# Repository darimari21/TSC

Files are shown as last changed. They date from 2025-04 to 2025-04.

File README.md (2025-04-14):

# TSC

Schema:

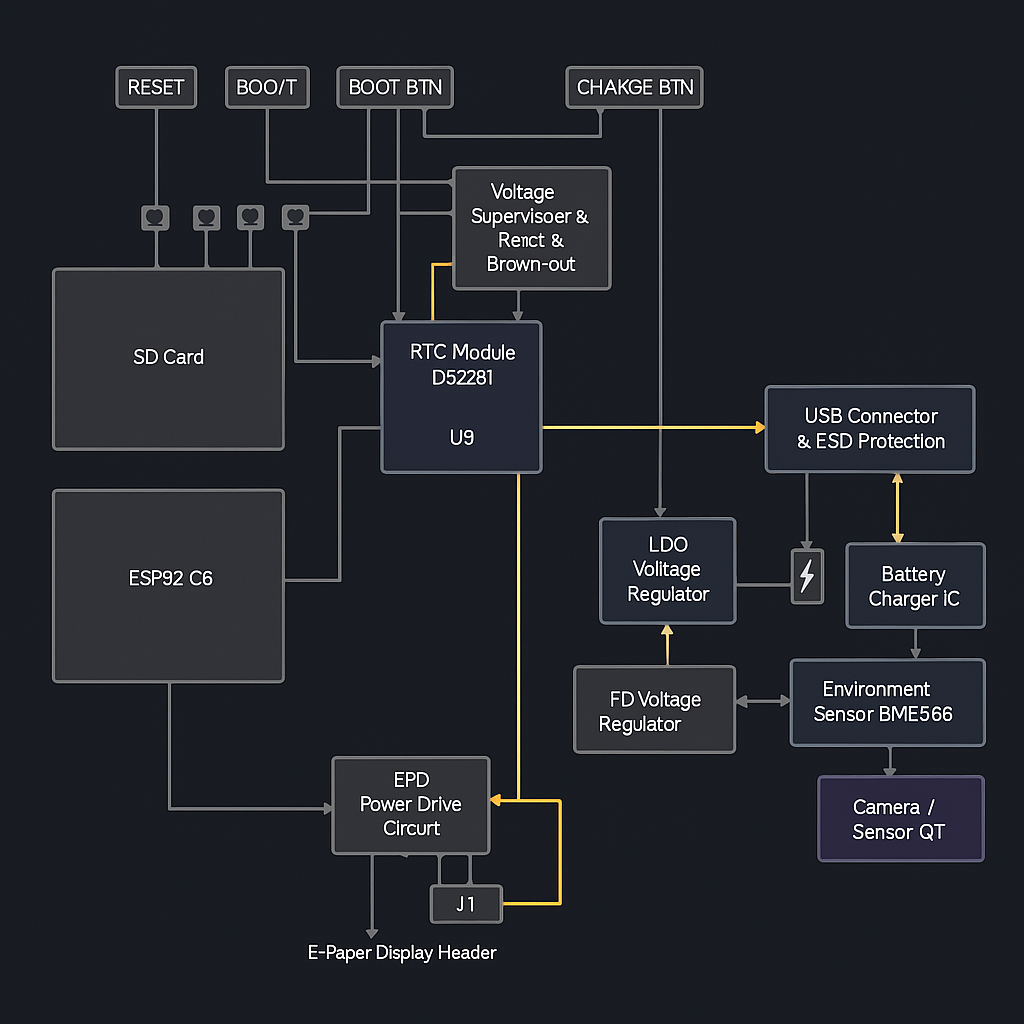
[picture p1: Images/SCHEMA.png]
Diagrama Bloc


Proiectul a început cu realizarea schemei electrice, folosind componentele din biblioteca pusă la dispoziție. După conectare și etichetare, am rulat ERC, corectând majoritatea erorilor (etichete greșite, pini suprapuși), rămânând cu una nedetectată de Fusion.
După finalizarea schemei, am trecut la PCB, decupând placa conform cerințelor și amplasând componentele. Cea mai mare provocare a fost identificarea pieselor și ajustarea unor footprint-uri, precum cel al bobinei L1. După rutare și verificare DRC, am completat cu planurile de masă pe ambele straturi.

Arhitectură Generală a Sistemului
Modulul ESP32-C6-WROOM-1-N8 servește drept unitate principală de control, gestionând comunicația cu celelalte module prin protocoale standard precum I2C, SPI și GPIO. Alimentarea este oferită de o baterie Li-Po, gestionată de un sistem de încărcare și monitorizare a nivelului energetic.

Specificații Hardware

Modul principal – ESP32-C6

Microcontroler cu arhitectură RISC-V, suport Wi-Fi 6 și Bluetooth Low Energy

Interfețe suportate: SPI, I2C, UART, GPIO

Tensiune de alimentare: 3.3V

Sistem de alimentare și monitorizare

MCP73831 – controller pentru încărcarea bateriei Li-Po

MAX17048 – circuit pentru monitorizarea nivelului bateriei (fuel gauge) cu ieșire de alertă

XC6220A331MR – regulator de tensiune pentru stabilizarea la 3.3V

Senzori și ceas de timp real

BME688 – senzor multifuncțional pentru temperatură, umiditate, presiune și compuși volatili (VOC), comunicare I2C

DS3231SN – modul RTC cu funcție de alarmă, conectat prin I2C

Afișaj și memorie
Display e-paper – eficient energetic, ideal pentru afișarea informațiilor statice

W25Q512JVEIQ – memorie SPI externă de tip NOR, capacitate 64Mbit

Slot pentru card SD – conectare opțională prin magistrala SPI partajată

Protecție și comunicație

USBLC6 – protecție ESD pentru liniile USB

Diode Schottky – protecție împotriva supratensiunii

Conector USB-C – folosit atât pentru alimentare, cât și pentru comunicație serială

Elemente de interacțiune cu utilizatorul

Buton de resetare (RESET)

LED indicator – semnalizează starea încărcării

Configurația Pinilor ESP32-C6
Componentă	Pin ESP32	Funcție

BME688 – SDA	IO8	Linie date I2C

BME688 – SCL	IO9	Linie ceas I2C

DS3231SN – INT	IO10	Semnal întrerupere RTC

W25Q512 – CS	IO4	Selectare chip SPI Flash

E-paper – CS	IO3	Selectare chip SPI Display

SPI – CLK	IO5	Semnal ceas SPI

SPI – MOSI	IO6	Date de la master la slave

SPI – MISO	IO7	Date de la slave la master

MAX17048 – ALERT	IO11	Semnal alertă baterie

Buton RESET	IO0	Reset / Boot

SD Card – CS	IO2	Selectare chip card SD

## BOM (Bill Of Materials)

| Componenta | Link Cumparare | Datasheet 
|---|---|---
| 112A-TAAR-R03 ATTEND | https://store.comet.srl.ro/Catalogue/Product/43497/ | https://www.snapeda.com/parts/112A-TAAR-R03/Attend/datasheet/ 
| BD5229G-TR | https://www.digikey.com/en/products/detail/rohm-semiconductor/BD5229G-TR/3663792 | https://fscdn.rohm.com/en/products/databook/datasheet/ic/power/voltage_detector/bd52xxg-e.pdf 
| ESP32 WROVER BME680 Sensor | https://store.comet.srl.ro/Catalogue/Product/50164/ | https://www.bosch-sensortec.com/media/boschsensortec/downloads/datasheets/bst-bme680-ds001.pdf 
| LED CHG_LED | https://ro.mouser.com/ProductDetail/Kingbright/KP-1608SURCK?qs=2JU0tDl2GZ3FuyEWfBV1%2Fg== | https://www.snapeda.com/parts/KP-1608SURCK/Kingbright/datasheet/ 
| Condensator C0402 | https://ro.mouser.com/c/passive-components/capacitors/ceramic-capacitors/?q=CC0402 | https://componentsearchengine.com/Datasheets/2/CC0402MRX5R5BB106.pdf 
| Condensator Tant | https://ro.mouser.com/ProductDetail/KYOCERA-AVX/TAJW107M010RNJ?qs=Wtp%252Bf%2FAeVqIH8v1VxV%252B1Rg%3D%3D | https://ro.mouser.com/datasheet/2/40/TAJ-3165264.pdf 
| Q1 DMG2305UX-7 | https://www.digikey.com/en/products/detail/diodes-incorporated/DMG2305UX-7/4340666 | https://www.diodes.com/assets/Datasheets/DMG2305UX.pdf 
| RTC MODULE DS3231SN# | https://www.snapeda.com/parts/DS3231SN%23/Analog+Devices/view-part/?ref=eda | https://www.snapeda.com/parts/DS3231SN%23/Analog%20Devices/datasheet/ 
| ESP32 C6 WROOM-1-N8 | https://ro.mouser.com/ProductDetail/Espressif-Systems/ESP32-C6-WROOM-1-N8?qs=8Wlm6%252BaMh8ST02Gmwp74cw%3D%3D | https://www.snapeda.com/parts/ESP32-C6-WROOM-1-N8/Espressif%20Systems/datasheet/ 
| FH34SRJ-24S-0.5SH(99) | https://ro.mouser.com/ProductDetail/Hirose-Connector/FH34SRJ-24S-0.5SH99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 | https://www.snapeda.com/parts/FH34SRJ-24S-0.5SH(99)/Hirose%20Connector/datasheet/ 
| MAX 17048G+T10 | https://www.snapeda.com/parts/MAX17048G+T10/Analog+Devices/view-part/?ref=eda | https://www.snapeda.com/parts/MAX17048G+T10/Analog%20Devices/datasheet/ 
| MBR0530 Schottky Diode | https://www.snapeda.com/parts/MBR0530/Onsemi/view-part/?ref=snap | https://www.snapeda.com/parts/MBR0530/ON%20Semiconductor/datasheet/ 
| MCP73831 Power Management | https://www.snapeda.com/parts/MCP73831T-2ACI/OT/Microchip/datasheet/ | https://www.snapeda.com/parts/MCP73831T-2ACI/OT/Microchip/datasheet/ 
| PFMF.050.1 | https://ro.mouser.com/ProductDetail/EPCOS-TDK/B72520T0350K062?qs=dEfas%2FXlABIszF52uu7vrg%3D%3D | https://www.tdk-electronics.tdk.com/inf/75/db/CTVS_14/Surge_protection_series.pdf 
| PGB1010603MR | https://www.snapeda.com/parts/PGB1010603MR/Littelfuse/view-part/?ref=eda | https://www.snapeda.com/parts/PGB1010603MR/Littelfuse%20Inc./datasheet/ 
| QWIIC_RIGHT_ANGLE CONNECTOR | https://ro.mouser.com/ProductDetail/SparkFun/PRT-14417?qs=wd5RIQLrsJhgdz%2FpmZ%2F3GQ== | https://ro.mouser.com/datasheet/2/813/Qwiic_Connector_Datasheet-1223982.pdf 
| Rezistenta R0402 | https://grabcad.com/library/resistor-0402-1) | https://www.yageo.com/upload/media/product/products/datasheet/rchip/PYu-RC_Group_51_RoHS_L_12.pdf
| SD0805S020S1R0 | https://ro.mouser.com/ProductDetail/KYOCERA-AVX/SD0805S020S1R0?qs=jCA%252BPfw4LHbpkAoSnwrdjw%3D%3D | https://ro.mouser.com/datasheet/2/40/schottky-3165252.pdf 
| Si1308EDL-T1-GE3 MOSFET | https://www.snapeda.com/parts/SI1308EDL-T1-GE3/Vishay+Siliconix/view-part/?welcome=home&ref=eda | https://www.snapeda.com/parts/SI1308EDL-T1-GE3/Vishay%20Siliconix/datasheet/ 
| USB4110-GF-A | https://ro.mouser.com/ProductDetail/GCT/USB4110-GF-A?qs=KUoIvG%2F9IlYiZvIXQjyJeA%3D%3D | https://ro.mouser.com/datasheet/2/837/GCT_USB4110_Product_Drawing___20k_cycles-3455479.pdf 
| USBLC6-2SC6Y | https://ro.mouser.com/ProductDetail/STMicroelectronics/USBLC6-2SC6Y?qs=gNDSiZmRJS%2FOgDexvXkdow%3D%3D | https://ro.mouser.com/datasheet/2/389/usblc6_2sc6y-1852505.pdf 
| W25Q512JVEIQ | https://www.snapeda.com/parts/W25Q512JVEIQ/Winbond+Electronics/view-part/?ref=eda) | https://www.winbond.com/resource-files/W25Q512JV%20SPI%20RevB%2006252019%20KMS.pdf 
| XC6220A331MR-G | https://componentsearchengine.com/part-view/XC6220A331MR-G/Torex | https://product.torexsemi.com/system/files/series/xc6220.pdf 
| 744043680 BOBINA | https://ro.mouser.com/ProductDetail/Wurth-Elektronik/744043680?qs=PGXP4M47uW6VkZq%252BkzjrHA%3D%3D | https://www.we-online.com/components/products/datasheet/744043680.pdf 

---

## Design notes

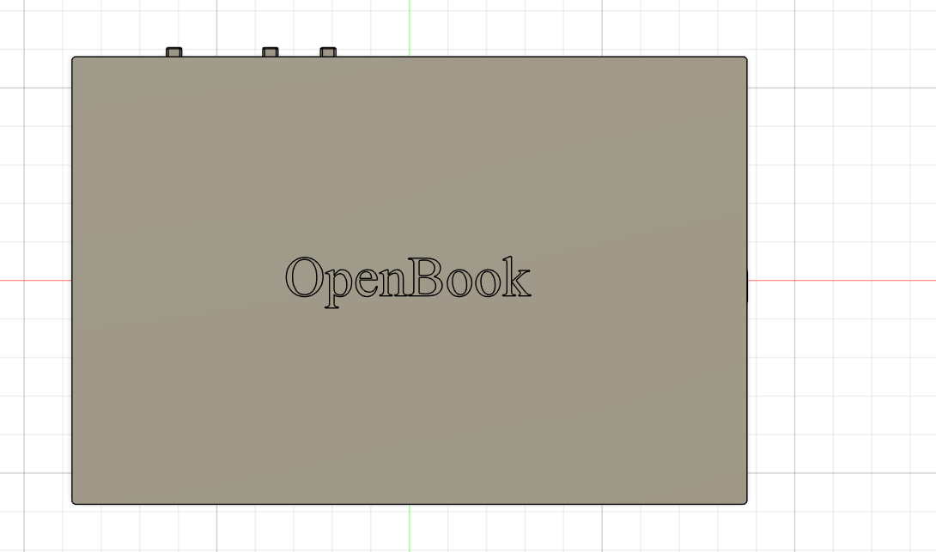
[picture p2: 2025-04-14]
Images/Screenshot 2025-04-14 142246.png

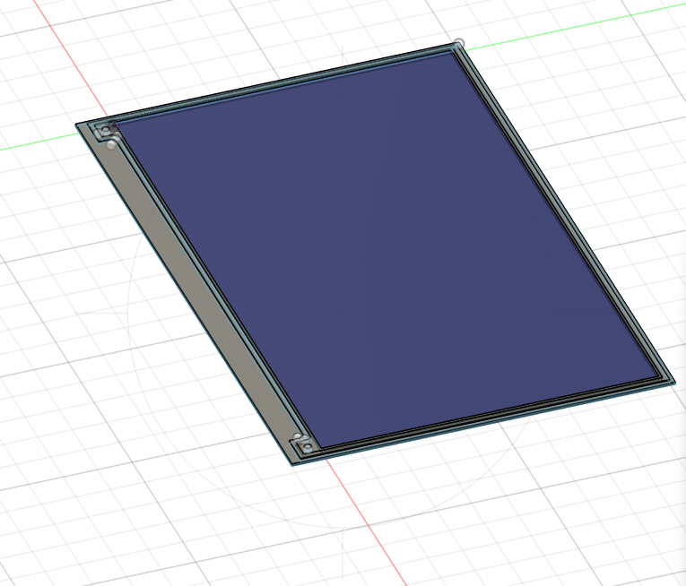
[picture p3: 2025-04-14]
Images/Screenshot 2025-04-14 142024.png

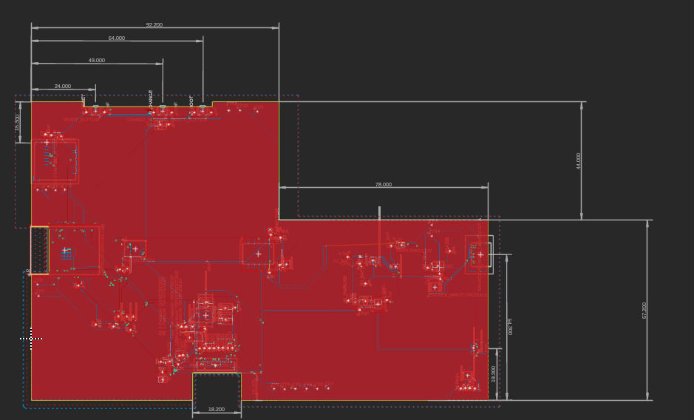
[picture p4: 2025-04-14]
Images/Screenshot 2025-04-14 141415.png

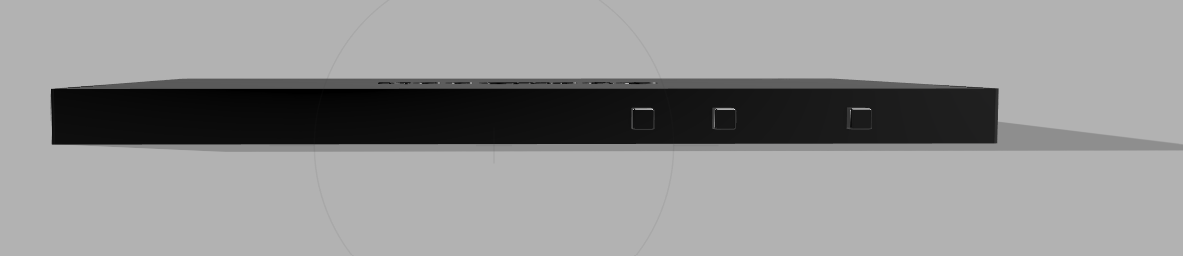
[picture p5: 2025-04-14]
Images/Screenshot 2025-04-14 140922.png

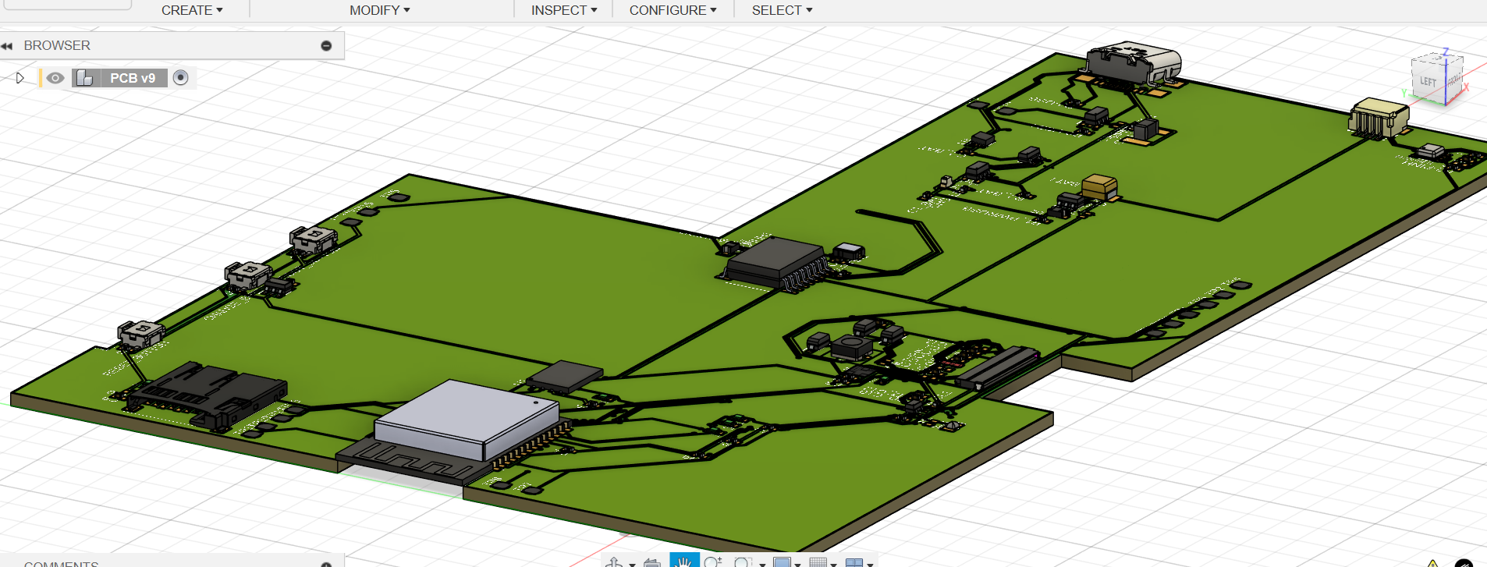
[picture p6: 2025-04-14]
Images/Screenshot 2025-04-14 141822.png

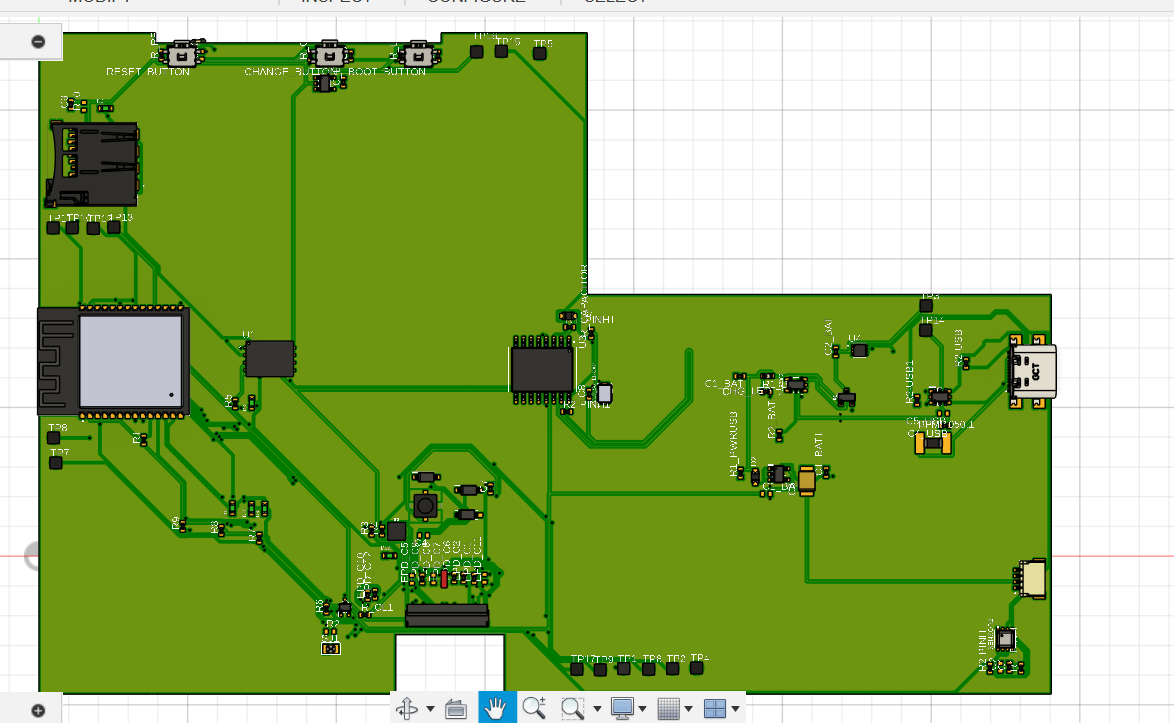
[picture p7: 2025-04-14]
Images/Screenshot 2025-04-14 141654.png

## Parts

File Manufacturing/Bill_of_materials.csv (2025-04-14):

Qty | Value | Device | Package | Parts | Description | ARROW_PART_NUMBER | ARROW_PRICE-STOCK | AVAILABILITY | CENTROID_NOT_SPECIFIED | CHECK_PRICES | COPYRIGHT | DATASHEET | DESCRIPTION | DIGIKEY_DESCRIPTION | DIGIKEY_PART_NUMBER | HEIGHT | LEAD_FREE | MANUFACTURER_NAME | MANUFACTURER_PART_NUMBER | MF | MFR_NAME | MOUSER_PART_NUMBER | MOUSER_PRICE-STOCK | MOUSER_TESTING_PART_NUMBER | MOUSER_TESTING_PRICE-STOCK | MP | MPN | PACKAGE | POPULARITY | PREFIX | PRICE | PROD_ID | PURCHASE-URL | ROHS | SNAPEDA_LINK | SPICEMODEL | SPICEPREFIX | TEMPERATURE_RANGE_HIGH | TEMPERATURE_RANGE_LOW | TP_SIGNAL_NAME | VALUE
1 |  | ADAFRUIT_LEDCHIP-LED0603 | ADAFRUIT_CHIP-LED0603 | CHG_LED | LED
1 |  | SJ | SJ | SJ1 | SMD solder JUMPER |  |  |  |  |  |  |  |  |  |  |  |  |  |  |  |  |  |  |  |  |  |  |  | 3
1 | 0.1uF/50v | EAGLE-LTSPICE_CC0402 | EAGLE-LTSPICE_C0402 | EPD_C5 | CAPACITOR, European symbol |  |  |  |  |  |  |  |  |  |  |  |  |  |  |  |  |  |  |  |  |  |  |  |  |  |  |  |  |  |  | NONE | C
1 | 0.47 | ESP32_WROVER_EAGLE-LTSPICE_RR0402 | ESP32_WROVER_EAGLE-LTSPICE_R0402 | R3 | RESISTOR, European symbol |  |  |  |  |  |  |  |  |  |  |  |  |  |  |  |  |  |  |  |  |  |  |  |  |  |  |  |  |  |  | NONE | R
1 | 100K | ESP32_WROVER_EAGLE-LTSPICE_RR0402 | ESP32_WROVER_EAGLE-LTSPICE_R0402 | R1_PWRUSB | RESISTOR, European symbol |  |  |  |  |  |  |  |  |  |  |  |  |  |  |  |  |  |  |  |  |  |  |  |  |  |  |  |  |  |  | NONE | R
8 | 100nF | EAGLE-LTSPICE_CC0402 | EAGLE-LTSPICE_C0402 | C1, C2, C4_USB, C6, C8, C9, C10, C_DELAY | CAPACITOR, European symbol |  |  |  |  |  |  |  |  |  |  |  |  |  |  |  |  |  |  |  |  |  |  |  |  |  |  |  |  |  |  | NONE | C
1 | 100uF TANT | RCL_CPOL-EUCT3528 | RCL_CT3528 | C3 | POLARIZED CAPACITOR, European symbol |  |  |  |  |  |  |  |  |  |  |  |  |  |  |  |  |  |  |  |  |  |  |  | 0 |  |  |  |  |  |  |  | C
11 | 10K | ESP32_WROVER_EAGLE-LTSPICE_RR0402 | ESP32_WROVER_EAGLE-LTSPICE_R0402 | R1_PINH, R1_PINH1, R2-PINH, R2-PINH1, R4, R5, R6, R7, R8, R9, R_CL1 | RESISTOR, European symbol |  |  |  |  |  |  |  |  |  |  |  |  |  |  |  |  |  |  |  |  |  |  |  |  |  |  |  |  |  |  | NONE | R
5 | 10k | ESP32_WROVER_EAGLE-LTSPICE_RR0402 | ESP32_WROVER_EAGLE-LTSPICE_R0402 | R1, R10, R_BOOT, R_CHANGE, R_RESET | RESISTOR, European symbol |  |  |  |  |  |  |  |  |  |  |  |  |  |  |  |  |  |  |  |  |  |  |  |  |  |  |  |  |  |  | NONE | R
1 | 10uF | EAGLE-LTSPICE_CC0402 | EAGLE-LTSPICE_C0402 | C7 | CAPACITOR, European symbol |  |  |  |  |  |  |  |  |  |  |  |  |  |  |  |  |  |  |  |  |  |  |  |  |  |  |  |  |  |  | NONE | C
1 | 112A-TAAR-R03_ATTEND | 112A-TAAR-R03_ATTEND | 112ATAARR03ATTEND | J4 | Micro SD Card Socket, Push-Push Type, Top Mount, SMT, H=1.83mm, 10u |  |  |  |  |  |  |  | Micro SD Card Socket | Push-Push Type | Top Mount | SMT | H=1.83mm | 10u |  |  | 1.9mm |  | ATTEND | 112A-TAAR-R03 ATTEND
1 | 15 | ESP32_WROVER_EAGLE-LTSPICE_RR0402 | ESP32_WROVER_EAGLE-LTSPICE_R0402 | R_CAPACITOR | RESISTOR, European symbol |  |  |  |  |  |  |  |  |  |  |  |  |  |  |  |  |  |  |  |  |  |  |  |  |  |  |  |  |  |  | NONE | R
1 | 1uF | EAGLE-LTSPICE_CC0402 | EAGLE-LTSPICE_C0402 | C5 | CAPACITOR, European symbol |  |  |  |  |  |  |  |  |  |  |  |  |  |  |  |  |  |  |  |  |  |  |  |  |  |  |  |  |  |  | NONE | C
9 | 1uF/50V | EAGLE-LTSPICE_CC0402 | EAGLE-LTSPICE_C0402 | EPD_C1, EPD_C2, EPD_C6, EPD_C7, EPD_C8, EPD_C9, EPD_C10, EPD_C11, EPD_C12 | CAPACITOR, European symbol |  |  |  |  |  |  |  |  |  |  |  |  |  |  |  |  |  |  |  |  |  |  |  |  |  |  |  |  |  |  | NONE | C
1 | 2.2 | ESP32_WROVER_EAGLE-LTSPICE_RR0402 | ESP32_WROVER_EAGLE-LTSPICE_R0402 | R2 | RESISTOR, European symbol |  |  |  |  |  |  |  |  |  |  |  |  |  |  |  |  |  |  |  |  |  |  |  |  |  |  |  |  |  |  | NONE | R
1 | 200 | ESP32_WROVER_EAGLE-LTSPICE_RR0402 | ESP32_WROVER_EAGLE-LTSPICE_R0402 | R1_BAT | RESISTOR, European symbol |  |  |  |  |  |  |  |  |  |  |  |  |  |  |  |  |  |  |  |  |  |  |  |  |  |  |  |  |  |  | NONE | R
2 | 20V/4.2A/52mO/1.4W | ESP32_WROVER_SPARKFUN-DISCRETESEMI_MOSFET_PCH-DMG2305UX-7 | ESP32_WROVER_SPARKFUN-DISCRETESEMI_SOT23-3 | Q1, Q2 | P-channel MOSFETs |  |  |  |  |  |  |  |  |  |  |  |  |  |  |  |  |  |  |  |  |  |  |  |  |  |  | TRAN-14388 |  |  |  |  |  |  |  |  | 20V/4.2A/52mO/1.4W
1 | 2K | ESP32_WROVER_EAGLE-LTSPICE_RR0402 | ESP32_WROVER_EAGLE-LTSPICE_R0402 | R2_BAT | RESISTOR, European symbol |  |  |  |  |  |  |  |  |  |  |  |  |  |  |  |  |  |  |  |  |  |  |  |  |  |  |  |  |  |  | NONE | R
3 | 4.7uF | EAGLE-LTSPICE_CC0402 | EAGLE-LTSPICE_C0402 | C1_BAT, C2_BAT, C5_USB | CAPACITOR, European symbol |  |  |  |  |  |  |  |  |  |  |  |  |  |  |  |  |  |  |  |  |  |  |  |  |  |  |  |  |  |  | NONE | C
2 | 4.7uF | ESP32_WROVER_EAGLE-LTSPICE_CC0402 | ESP32_WROVER_EAGLE-LTSPICE_C0402 | C1_BAT1, C1_BAT2 | CAPACITOR, European symbol |  |  |  |  |  |  |  |  |  |  |  |  |  |  |  |  |  |  |  |  |  |  |  |  |  |  |  |  |  |  | NONE | C
1 | 4.7uF/25V | EAGLE-LTSPICE_CC0402 | EAGLE-LTSPICE_C0402 | C4 | CAPACITOR, European symbol |  |  |  |  |  |  |  |  |  |  |  |  |  |  |  |  |  |  |  |  |  |  |  |  |  |  |  |  |  |  | NONE | C
1 | 5K1 | ESP32_WROVER_EAGLE-LTSPICE_RR0402 | ESP32_WROVER_EAGLE-LTSPICE_R0402 | R2-USB1 | RESISTOR, European symbol |  |  |  |  |  |  |  |  |  |  |  |  |  |  |  |  |  |  |  |  |  |  |  |  |  |  |  |  |  |  | NONE | R2-USB1
1 | 5k1 | ESP32_WROVER_EAGLE-LTSPICE_RR0402 | ESP32_WROVER_EAGLE-LTSPICE_R0402 | R2-USB | RESISTOR, European symbol |  |  |  |  |  |  |  |  |  |  |  |  |  |  |  |  |  |  |  |  |  |  |  |  |  |  |  |  |  |  | NONE | R
1 | 68uH | 744043680IND_4828-WE-TPC_WRE | IND_4828-WE-TPC_WRE | L1 |  |  |  |  |  |  | Copyright (C) 2024 Ultra Librarian. All rights reserved. |  |  |  |  |  |  |  | 744043680 |  | Wurth Electronics
1 | BD5229G-TR | BD5229G-TR | SOT95P280X125-5N | IC1 | Voltage Detector with Adjustable Delay Time: CMOS processes are utilized to develop high precision, low current consumption CMOS reset ICs that allow arbitrary setting of the delay time. The extensive lineup includes both Nch Open Drain and CMOS output types in a wide range of detection voltages (from 2.3V to 6.0V, in 0.1V steps), enabling selection of the ideal solution based on customer requirements. In addition, the entire series is of course both lead-free and RoHS-compliant. |  |  |  |  |  |  |  | Voltage Detector with Adjustable Delay Time: CMOS processes are utilized to develop high precision | low current consumption CMOS reset ICs that allow arbitrary setting of the delay time. The extensive lineup includes both Nch Open Drain and CMOS output types in a wide range of detection voltages (from 2.3V to 6.0V | in 0.1V steps) | enabling selection of the ideal solution based on customer requirements. In addition | the entire series is of course both lead-free and RoHS-compliant. |  |  | 1.25mm |  | ROHM Semiconductor | BD5229G-TR |  |  | 755-BD5229G-TR | https://www.mouser.co.uk/ProductDetail/ROHM-Semiconductor/BD5229G-TR?qs=4kLU8WoGk0vvnhrrYwdszw%3D%3D
3 | BUTTON_CUSYOMV1 | BUTTON_CUSYOMV1 | MYBUTTON | BOOT_BUTTON, CHANGE_BUTTON, RESET_BUTTON
1 | CPH3225A | CPH3225A | CAPCP3225X100N | C10_SUPERCAP | Cap 0.011F 3.3V 1210 Flat Check availability |  |  | Not in stock |  | https://www.snapeda.com/parts/CPH3225A/Seiko+Instruments/view-part/?ref=eda |  |  | 11 mF (EDLC) Supercapacitor 3.3 V 1210 (3225 Metric) - - |  |  |  |  |  |  | Seiko Instruments |  |  |  |  |  | CPH3225A |  | 1210 Seiko |  |  | None |  | https://www.snapeda.com/api/url_track_click_mouser/?unipart_id=562593&manufacturer=Seiko Instruments&part_name=CPH3225A&search_term=None |  | https://www.snapeda.com/parts/CPH3225A/Seiko+Instruments/view-part/?ref=snap
1 | DS3231SN# | DS3231SN# | SOIC127P1032X265-16N | U3 | Real Time Clock Serial 16-Pin SOIC W T/R Check availability |  |  | In Stock |  | https://www.snapeda.com/parts/DS3231SN%23/Analog+Devices/view-part/?ref=eda |  |  | Extremely Accurate I²C-Integrated RTC/TCXO/Crystal |  |  |  |  |  |  | Analog Devices |  |  |  |  |  | DS3231SN# |  | SOIC-16 Maxim |  |  | None |  | https://www.snapeda.com/api/url_track_click_mouser/?unipart_id=99048&manufacturer=Analog Devices&part_name=DS3231SN#&search_term=None |  | https://www.snapeda.com/parts/DS3231SN%23/Analog+Devices/view-part/?ref=snap
1 | ESP32-C6-WROOM-1-N8 | ESP32-C6-WROOM-1-N8 | XCVR_ESP32-C6-WROOM-1-N8 | U2 | Check availability |  |  | In Stock |  | https://www.snapeda.com/parts/ESP32-C6-WROOM-1-N8/Espressif+Systems/view-part/?ref=eda |  |  | Multiprotocol Modules ESP32-C6 module | Wi-Fi 6 in 2.4 GHz band | Bluetooth 5 | Zigbee 3.0 and Thread. ESP34-WROOM Compatible - ENGINEERING SAMPLE |  |  |  |  |  |  | Espressif Systems |  |  |  |  |  | ESP32-C6-WROOM-1-N8 |  | None |  |  | None |  |  |  | https://www.snapeda.com/parts/ESP32-C6-WROOM-1-N8/Espressif+Systems/view-part/?ref=snap
1 | ESP32C6_VARISTORCN1812 | ESP32C6_VARISTORCN1812 | ESP32C6_VARISTOR_CT/CN1812 | PFMF.050.1 | VARISTOR |  |  |  |  |  |  |  |  |  |  |  |  |  |  |  |  |  |  |  |  |  |  |  | 0
2 | ESP32_WROVER_AVX---SD0805S020S1R0_AVX_SD0805S020S1R0_0_0AVX_SD0805S020S1R0_0_0 | ESP32_WROVER_AVX---SD0805S020S1R0_AVX_SD0805S020S1R0_0_0AVX_SD0805S020S1R0_0_0 | ESP32_WROVER_AVX---SD0805S020S1R0_AVX_SD0805S020S1R0_0 | D2, D7 | Schottky Barrier Rectifier Diode |  |  |  | No |  |  | http://datasheets.avx.com/schottky.pdf |  | DIODE SCHOTTKY 20V 1A 0805 | 478-7800-1-ND |  | yes |  |  | AVX |  | 581-SD0805S020S1R0 |  |  |  |  |  | 0805 (2012 metric) |  | D |  |  |  | yes |  |  |  | +125°C | -55°C
1 | ESP32_WROVER_BME680_BME680 | ESP32_WROVER_BME680_BME680 | ESP32_WROVER_BME680_PSON80P300X300X100-8N | SENSOR2 | Integrated Environmental Unit |  |  | Unavailable |  |  |  |  | Integrated Environmental Unit |  |  |  |  |  |  | Bosch Sensortec |  |  |  |  |  | BME680 |  | LGA-8 Bosch Tools |  |  | None
1 | ESP32_WROVER_SPARKFUN-IC-POWER_MCP73831 | ESP32_WROVER_SPARKFUN-IC-POWER_MCP73831 | ESP32_WROVER_SPARKFUN-IC-POWER_SOT23-5 | MCP73831 | MCP73831T Li-Ion, Li-Pol Controller |  |  |  |  |  |  |  |  |  |  |  |  |  |  |  |  |  |  |  |  |  |  |  |  |  |  | IC-09995
1 | FH34SRJ-24S-0.5SH_99_ | FH34SRJ-24S-0.5SH_99_ | FH34SRJ24S05SH99 | J1 | (0.50mm) Surface Mount, Right Angle |  |  |  |  |  |  |  | 24 Position FFC | FPC Connector Contacts | (0.50mm) Surface Mount | Right Angle |  |  | 1.1mm |  | Hirose | FH34SRJ-24S-0.5SH(99) |  |  | 798-FH34SRJ24S05SH99 | https://www.mouser.co.uk/ProductDetail/Hirose-Connector/FH34SRJ-24S-0.5SH99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
1 | MAX17048G+T10 | MAX17048G+T10 | SON50P200X200X80-9N | U4 | Check availability |  |  | In Stock |  | https://www.snapeda.com/parts/MAX17048G+T10/Analog+Devices/view-part/?ref=eda |  |  | 3µA 1-Cell/2-Cell Fuel Gauge with ModelGauge |  |  |  |  |  |  | Analog Devices |  |  |  |  |  | MAX17048G+T10 |  | TDFN-8 Maxim |  |  | None |  | https://www.snapeda.com/api/url_track_click_mouser/?unipart_id=329239&manufacturer=Analog Devices&part_name=MAX17048G+T10&search_term=None |  | https://www.snapeda.com/parts/MAX17048G+T10/Analog+Devices/view-part/?ref=snap
3 | MBR0530 | MBR0530 | SOD3716X135N | D3, D4, D5 | ON SEMICONDUCTOR - MBR0530 - DIODE, SCHOTTKY, 0.5A, 30V, SOD-123 |  |  | In Stock |  | https://www.snapeda.com/parts/MBR0530/Onsemi/view-part/?ref=eda |  |  | Diode Schottky 30 V 500mA Surface Mount SOD-123 |  |  |  |  |  |  | ON Semiconductor |  |  |  |  |  | MBR0530 |  | SOD-123-2 ON Semiconductor |  |  | None |  | https://www.snapeda.com/api/url_track_click_mouser/?unipart_id=179458&manufacturer=ON Semiconductor&part_name=MBR0530&search_term=None |  | https://www.snapeda.com/parts/MBR0530/Onsemi/view-part/?ref=snap
6 | PGB1010603MR | PGB1010603MR | DIOC1608X36N | D6, D8, D9, D10, D11, D12 | Check availability |  |  | In Stock |  | https://www.snapeda.com/parts/PGB1010603MR/Littelfuse/view-part/?ref=eda |  |  | 150V (Typ) Clamp - Ipp Tvs Diode Surface Mount 0603 (1608 Metric) |  |  |  |  |  |  | Littelfuse Inc. |  |  |  |  |  | PGB1010603MR |  | 0603 Littelfuse Inc. |  |  | None |  | https://www.snapeda.com/api/url_track_click_mouser/?unipart_id=5659453&manufacturer=Littelfuse Inc.&part_name=PGB1010603MR&search_term=None |  | https://www.snapeda.com/parts/PGB1010603MR/Littelfuse/view-part/?ref=snap
1 | QWIIC_RIGHT_ANGLE | QWIIC_CONNECTORJS-1MM | JST04_1MM_RA | J3 | SparkFun I2C Standard Qwiic Connector |  |  |  |  |  |  |  |  |  |  |  |  |  |  |  |  |  |  |  |  |  |  |  |  |  |  | CONN-13694 |  |  |  |  |  |  |  |  | QWIIC_RIGHT_ANGLE
1 | SAMACSYS_PARTS_USB4110-GF-A | SAMACSYS_PARTS_USB4110-GF-A | SAMACSYS_PARTS_USB4110GFA | J2 | CONN USB 2.0 TYPE-C R/A SMT |  |  |  |  |  |  |  | CONN USB 2.0 TYPE-C R/A SMT |  |  | 3.26mm |  | GCT (GLOBAL CONNECTOR TECHNOLOGY) | USB4110-GF-A |  |  | 640-USB4110-GF-A | https://www.mouser.co.uk/ProductDetail/GCT/USB4110-GF-A?qs=KUoIvG%2F9IlYiZvIXQjyJeA%3D%3D
1 | SI1308EDL-T1-GE3 | SI1308EDL-T1-GE3 | SOT65P210X110-3N | Q3 | MOSFET N-Ch 30V 1.5A TrenchFET SC70 Vishay Si1308EDL-T1-GE3 N-channel MOSFET Transistor, 1.5 A, 30 V, 3-Pin SC-70 |  |  | In Stock |  | https://www.snapeda.com/parts/SI1308EDL-T1-GE3/Vishay+Siliconix/view-part/?ref=eda |  |  | Si1308EDL-T1-GE3 N-channel MOSFET Transistor | 1.5 A | 30 V | 3-Pin SC-70 | Siliconix / Vishay SI1308EDL-T1-GE3 |  |  |  |  |  |  | Vishay Siliconix |  |  |  |  |  | SI1308EDL-T1-GE3 |  | SOT-323 Vishay Semiconductor |  |  | None |  | https://www.snapeda.com/api/url_track_click_mouser/?unipart_id=274603&manufacturer=Vishay Siliconix&part_name=SI1308EDL-T1-GE3&search_term=None |  | https://www.snapeda.com/parts/SI1308EDL-T1-GE3/Vishay+Siliconix/view-part/?ref=snap
17 | TPTP20R | TPTP20R | TP20R | TP1, TP2, TP3, TP4, TP5, TP6, TP7, TP8, TP9, TP10, TP11, TP12, TP13, TP14, TP15, TP16, TP17 | Test pad |  |  |  |  |  |  |  |  |  |  |  |  |  |  |  |  |  |  |  |  |  |  |  | 2
1 | USBLC6-2SC6Y | USBLC6-2SC6Y | SOT95P280X145-6N | D1 | Low Cap. ESD Protection Auto SOT-23-6 STMicroelectronics USBLC6-2SC6Y, Dual Uni-Directional TVS Diode Array, 6-Pin SOT-23 |  |  | In Stock |  | https://www.snapeda.com/parts/USBLC6-2SC6Y/STMicroelectronics/view-part/?ref=eda |  |  | 17V Clamp 5A (8/20µs) Ipp Tvs Diode Surface Mount SOT-23-6 |  |  |  |  |  |  | STMicroelectronics |  |  |  |  |  | USBLC6-2SC6Y |  | SOT-23-6 STMicroelectronics |  |  | None |  |  |  | https://www.snapeda.com/parts/USBLC6-2SC6Y/STMicroelectronics/view-part/?ref=snap
1 | W25Q512JVEIQ | W25Q512JVEIQ | SON127P600X800X80-9N | U1 | Check availability |  |  | In Stock |  | https://www.snapeda.com/parts/W25Q512JVEIQ/Winbond+Electronics/view-part/?ref=eda |  |  | FLASH - NOR Memory IC 512Mb (64M x 8) SPI - Quad I/O 133 MHz 8-WSON (8x6) |  |  |  |  |  |  | Winbond Electronics |  |  |  |  |  | W25Q512JVEIQ |  | Package |  |  | None |  |  |  | https://www.snapeda.com/parts/W25Q512JVEIQ/Winbond+Electronics/view-part/?ref=snap
1 | XC6220A331MR-G | XC6220A331MR-G | SOT95P280X120-5N | IC4 | LDO Voltage Regulators |  |  |  |  |  |  |  | LDO Voltage Regulators |  |  | 1.2mm |  | Torex | XC6220A331MR-G |  |  | 865-XC6220A331MR-G | https://www.mouser.co.uk/ProductDetail/Torex-Semiconductor/XC6220A331MR-G?qs=AsjdqWjXhJ8ZSWznL1J0gg%3D%3D
